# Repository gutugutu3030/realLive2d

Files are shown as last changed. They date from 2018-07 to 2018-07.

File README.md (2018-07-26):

# realLive2d
gif
## reallive2dSimulator
Processing　設計ソフト＋シミュレータ

縮尺は 1pixel = 0.1mm
一応シリアル通信機能はついているがv1用　現状のプログラムでは使用できないので注意

使用ライブラリ：controlP5

## Servo16
Arduino実行ファイル．上記の理由に付き基本的にはこっちをいじったほうが良い
こっちはstandalone関数内に書くと良さげ
usingEEPROMフラグでレイヤの移動量をEEPROMから読むかソースコードの値を参照するかを決定できる

使用ライブラリ：秋月電子のPCA9685.zip，[Skywriter Arduino Library](https://github.com/pimoroni/skywriter-hat/tree/master/arduino)，[SparkFun GridEYE Arduino Library](https://github.com/sparkfun/SparkFun_GridEYE_Arduino_Library), EEPROM

## explore
顔のパラメータを変更可能　上記のEEPROMモードにてパラメータ書き込みをするソフトもこれが担当する

マウス座標に顔が向くようになっている　上のスライダにて各レイヤの移動量を変更できる．移動量はキー操作でEEPROMに書き込みができる

## timeline
5秒間，各レイヤの動きを記録，再生できる
簡単なタイムラインインターフェースからなっている
sキーで保存，lキーで読み込みが可能

## deteilsaver
キャリブレーション用システム
Servo16_deteilsaverを書き込んだ状態で起動することで，サーボの角度のキャリブレーションができる

## DOASerial.py
python2.7必須
Arduinoのシリアルポートに設定することで聴覚を与えることができる
use [ReSpeaker USB 4 Mic Array](https://github.com/respeaker/usb_4_mic_array/)

## 3dmodels
使用した3Dモデル一覧

| name | 説明 |
----|----
| hone.stl | サーボモータのホーン拡張用 |
| servoHone.scad | hone.stlの元データ |
| line.scad | 4連サーボのデータ　サーボのモデルデータ込 |
| v2.scad | v2プレートのデータ　要line.scad |
| v2.stl | v2プレートのデータ |
| v2-arm.scad | セパレータ（透明の板）を保持するアームfor v2 の元データ|
| v2-arm.stl | セパレータを保持するアームfor v2|

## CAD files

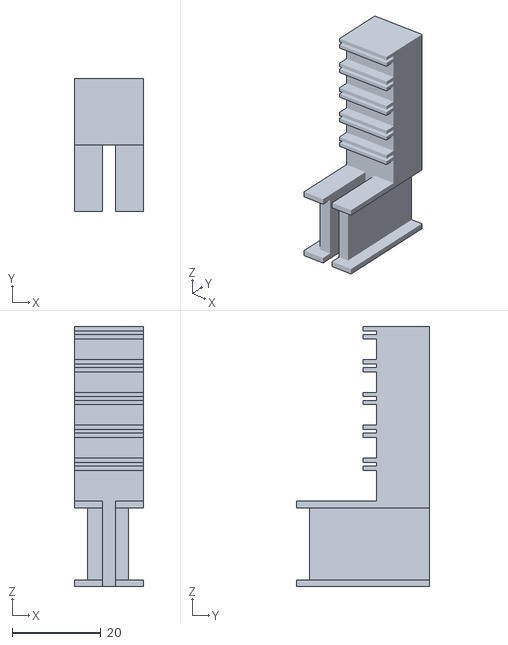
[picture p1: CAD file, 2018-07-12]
3dmodels/v2-arm.stl
15.6 x 30.0 x 58.5

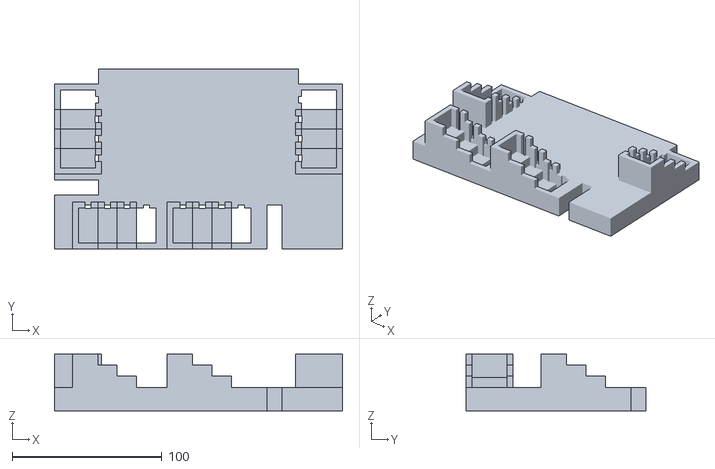
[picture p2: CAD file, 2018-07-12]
3dmodels/v2.stl
192.4 x 120.0 x 38.0

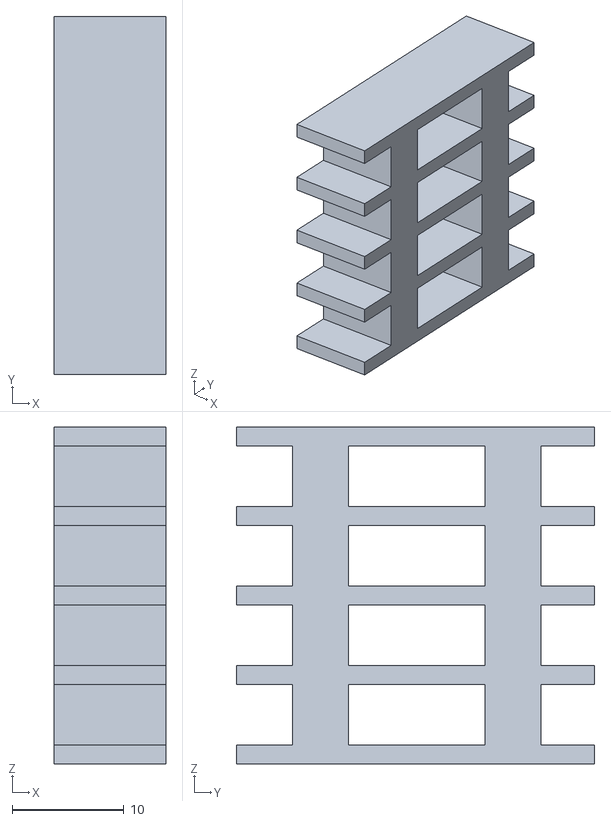
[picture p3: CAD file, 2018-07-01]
3dmodels/arm.stl
10.0 x 32.0 x 30.1

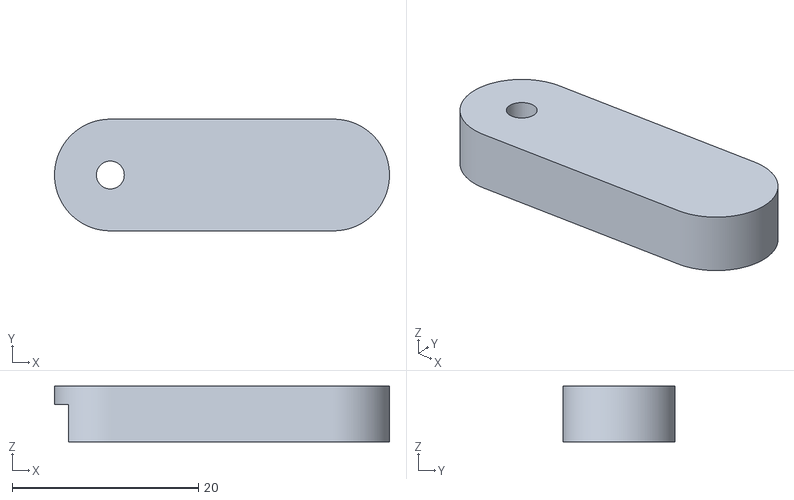
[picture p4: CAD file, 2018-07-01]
3dmodels/hone.stl
36.0 x 12.0 x 6.00

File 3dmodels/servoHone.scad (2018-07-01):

honeh=4;

difference(){
    union(){
        cylinder(r=6,h=6,$fn=180);
        translate([30-6,0,0])
        cylinder(r=6,h=6,$fn=180);
        translate([0,-6,0])
        cube([30-6,12,6]);
    }
    union(){
        translate([-10,-4,0])
        cube([30,8,honeh]);
        cylinder(r=1.5,h=100,$fn=50);
    }
}

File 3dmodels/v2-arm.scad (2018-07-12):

include<line.scad>
//echo(servo*4+waku*2-0.4);
//translate([-10,0,0])
//cube([10-0.4,servoH+waku-0.4,(2.4+5)*4+15.8+2.4]);
//hikkake(l=10-0.4,d=2,thin=1,fixPos=false);
//servo();


waku1=3;

difference(){
    union(){
        cube([10-0.4,servoH+waku-0.4,15.8+0.4]);
        translate([0,15,0])
        {
            cube([10-0.4,servoH+waku-0.4-15,(2.4+5)*5+15.8+2.4+1+0.8]);
            hikkake(l=10-0.4,d=3,thin=1,fixPos=false);
        }
        translate([-waku1,-waku1,-1.5])
            cube([10-0.4+waku1*2,servoH+waku-0.4+waku1,1.5]);
        translate([-waku1,-waku1,15.8+0.4])
            cube([10-0.4+waku1*2,servoH+waku-0.4+waku1,1.5]);
        //servo4_0();
    }
    translate([(10-0.4-5)/2,-waku1,-50])
    cube([5,15+waku1,70]);
}

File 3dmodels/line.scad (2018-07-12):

//cube([100,100,15.8]);

servoW=12.6+0.4;
servoH=23.0+0.4;
    waku=4;

module servo(){
    cube([12.6+0.4,23.0+0.4,26.7]);
    translate([0,(23.0-32.4)/2,15.8])
    cube([12.6+0.4,32.4,2.4]);
    translate([(13-4.2)/2,23,-100])
    cube([4.2,5,18+100]);
}

module servo4_0(){
translate([servoW*4,0,0])
scale([-1,1,1])
    for(i = [0:3]){
        translate([i*13,0,(2.4+5)*i]){
            servo();
        }
    }
}

module servo4(){
translate([servoW*4,0,0])
scale([-1,1,1])
difference(){
union(){
    translate([-waku,-waku,0])
    cube([waku,waku*2+servoH,15.8]);
    translate([0,-waku,0]){
    for(i = [0:3]){
        translate([i*13,0,0]){
            cube([waku+servoW,waku*2+servoH,15.8+(2.4+5)*i]);
        }
    }
    }
}


union(){
    for(i = [0:3]){
        translate([i*13,0,(2.4+5)*i]){
            servo();
        }
    }
    
}
}
}

module servo4_rect(l=servoW*4+waku*2){
    translate([-waku,-waku,0])
    cube([l,servoH+waku+2,15.8]);

}


module hikkake(l=servoW*4,d=10,fixPos=true,haba=0.8,thin=2){
    x=0;
    if(fixPos){
        x=-waku;
    }
    for(i=[1:5]){
        translate([0,-d,(2.4+5)*i+15.8+2.4-thin])
            cube([l,d,thin]);  
        translate([0,-d,(2.4+5)*i+15.8+2.4+haba])
            cube([l,d,thin]);  
    }

}

//servo4_0();
//servo();
//hikkake();
//

//for(i=[0:4]){
//translate([-waku,waku+servoH,(2.4+5)*i+15.8+2.4])
//cube([servoW*4,10,2]);
//}
//translate([-waku,waku+servoH,(2.4+5)+15.8+2.4])
//cube([servoW*2+waku,10,2]);
//translate([-waku,waku+servoH,(2.4+5)*2+15.8+2.4])
//cube([servoW+waku,10,2]);
//
//translate([100,0,0])
//servo4_rect();
//
//translate([0,50,0])
//servo4_rect();

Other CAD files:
3dmodels/v2.scad

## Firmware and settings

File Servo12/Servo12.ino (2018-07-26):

#include <EEPROM.h>
#include <Wire.h>
#include <SparkFun_GridEYE_Arduino_Library.h>
#include <PCA9685.h>            //PCA9685用ヘッダーファイル（秋月電子通商作成）
#include <skywriter.h>

bool usingEEPROM = true;

PCA9685 pwm = PCA9685(0x40);    //PCA9685のアドレス指定（アドレスジャンパ未接続時）

GridEYE grideye;//サーモセンサ

#define SERVOMIN 51            //最小パルス幅 (標準的なサーボパルスに設定)
#define SERVOMAX 255            //最大パルス幅 (標準的なサーボパルスに設定)
#define BUFFERSIZE 100
#define LAYER_LENGTH 3
#define SERVO_NUM 12

int amount[LAYER_LENGTH] = {30, -22, 50}; //usingEEPROM=falseのときに使用される値
int defaultAngle[SERVO_NUM] = {24, 35, 25, 18, 16, 24, 30, 23, 22, 23, 0, 23/*, 26, 13, 25, 31*/};
//レイヤー2可動サーボが時々プラ版に引っかかるため，動作を制限する
int maxmin[LAYER_LENGTH][2] = {{95, 0}, {100, 15}, {100, 0}};


//0 - 100
int layerX[LAYER_LENGTH] = {50, 50, 50};
int layerY[LAYER_LENGTH] = {50, 50, 50};


//開始命令＋終了命令：0
//1~181までの数値を受け取る

void setup() {
  Serial.begin(57600);
  delay(500);
  pwm.begin();                   //初期設定 (アドレス0x40用)
  pwm.setPWMFreq(20);            //PWM周期を60Hzに設定 (アドレス0x40用)
  delay(500);
  Skywriter.begin(4, 5);
  Skywriter.onXYZ(handle_xyz);
  delay(50);
  grideye.begin();
  if (usingEEPROM) {
  Serial.println("layerAmount:");
    for (int i = 0; i < LAYER_LENGTH; i++) {
      amount[i] = EEPROM[i] - 50;
      Serial.print(amount[i]);
      Serial.print(" ");
    }
    Serial.println();
  }
}

unsigned long lastReceivingTime = 0;

void loop() {
  if (Serial.available()) {
    byte buffer[BUFFERSIZE];
    int length = Serial.readBytesUntil(0, buffer, BUFFERSIZE);
    if (length != 0) {
      if (exploreEvent(buffer[0], buffer + 1, length - 1)) {
        lastReceivingTime = millis();
      }
    }
  }
  if (millis() - lastReceivingTime > 3000) {
    standalone();
  }
}


void servo_write(int ch, int ang) { //動かすサーボチャンネルと角度を指定
  ang = map(ang, 0, 180, SERVOMIN, SERVOMAX); //角度（0～180）をPWMのパルス幅（150～600）に変換
  pwm.setPWM(ch, 0, ang);
  //delay(1);
}

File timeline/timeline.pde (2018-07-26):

import controlP5.*;
import processing.serial.*;
import java.util.*;

final byte COMMAND_EXPLORE=0x01;
int layerNum=3;
boolean usingSerial=true;

Serial arduino;
ControlP5 cp5;

int timeIndex=0;
boolean playing=false;

Timeline t[]=new Timeline[layerNum*2];
Timeline selectedTimeline=null;

int amount[]=new int[layerNum*2];

void setup() {
  size(1600, 1600);
  cp5 = new ControlP5(this);
  for (int i=0; i<t.length; i++) {
    t[i]=new Timeline(50, i*200, width-200, 200, 100);
    cp5.addSlider("layerAmount_"+i).setPosition(width-100, i*200).setSize(100, 180).setRange(-50, 50).setValue(amount[i]).setId(i);
  }
  if (usingSerial) {
    arduino=new Serial(this, "COM8", 57600);
  }

  frameRate(60);
}

void draw() {
  if (playing&&frameCount%3==0) {
    timeIndex++;
  }

  for (Timeline t1 : t) {
    t1.draw();
  }
  strokeWeight(3);
  stroke(0);
  for (int i=0; i<layerNum*2; i++) {
    line(0, i*200, width, i*200);
  }
  if (usingSerial&&frameCount%5==0) {
    arduino.write(COMMAND_EXPLORE);
    for (int i=0; i<layerNum*2; i++) {
      arduino.write(t[i].getValue(amount[i]));
      print(t[i].getValue(amount[i])+" ");
    }
    println();
    arduino.write(0);
  }
}

void mousePressed() {
  for (Timeline t1 : t) {
    if (t1.ifin()) {
      selectedTimeline=t1;
      break;
    }
  }
}

void mouseDragged() {
  if (selectedTimeline!=null) {
    selectedTimeline.drag();
  }
}

void mouseReleased(){
  selectedTimeline=null;
}

void keyReleased() {
  if (key==' ') {
    if (playing) {
      playing=false;
    } else {
      playing=true;
      timeIndex=0;
    }
  }
  if (key=='s') {
    String lines[]=new String[layerNum*2];
    for (int i=0; i<lines.length; i++) {
      lines[i]="";
      for (int j=0; j<t[i].data.length; j++) {
        if (j!=0) {
          lines[i]+=",";
        }
        lines[i]+=t[i].data[j];
      }
      lines[i]+=":"+amount[i];
    }
    saveStrings("data.text", lines);
  }
  if (key=='l') {
    String lines[]=loadStrings("data.text");
    for (int i=0; i<lines.length; i++) {
      String sp[]=lines[i].split(":");
      String data[]=sp[0].split(",");
      for (int j=0; j<data.length; j++) {
        t[i].data[j]=int(data[j]);
      }
      amount[i]=int(sp[1]);
      cp5.getController("layerAmount_"+i).setValue(amount[i]);
    }
  }
}

class Timeline {
  int data[];
  int width, height;
  int x, y;
  float scale=1;
  Timeline(int x, int y, int width, int height, int dataLength) {
    data=new int[dataLength];
    scale=1.0*(dataLength-1)/(width-1);
    this.width=width;
    this.height=height;
    this.x=x;
    this.y=y;
  }
  void draw() {
    strokeWeight(1);
    stroke(0);
    fill(255);
    rect(x, y, width, height);
    stroke(200);
    line(x, y+height/2, x+width, y+height/2);
    strokeWeight(2);
    noFill();
    stroke(0, 0, 100);
    beginShape();
    for (int i=0; i<data.length; i++) {
      vertex(x+i/scale, y+height/2-data[i]);
    }
    endShape();
    strokeWeight(1);
    stroke(255, 0, 0);
    {
      int x1=(int)(x+timeIndex%data.length/scale);
      line(x1, y, x1, y+height);
    }
  }
  void drag() {
    int x1=min(max(mouseX-x, 0), width-1);
    int y1=height/2-min(max(mouseY-y, 0), height);
    data[(int)(x1*scale)]=y1;
  }
  boolean ifin() {
    return x<=mouseX&&mouseX<x+width&&y<=mouseY&&mouseY<y+height;
  }
  int getValue(int amount) {
    //println((timeIndex%data.length)+" "+data[timeIndex%data.length]);
    return data[timeIndex%data.length]*amount/height+51;
  }
}

void controlEvent(ControlEvent theEvent) {
  if (theEvent.isController()) {
    // check if theEvent is coming from a boxsize controller
    if (theEvent.controller().getName().startsWith("layerAmount_")) {
      // get the id of the controller and map the value
      // to an element inside the boxsize array.
      int id = theEvent.controller().getId();
      if (id>=0 && id<amount.length) {
        amount[id] = (int)theEvent.getValue();
      }
    }
  }
}

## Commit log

2018-07-01 テストコード
2018-07-01 add 3dmodel
    [arm.stl, hone.stl, servoHone.scad]
2018-07-02 skywriter追加
    RCフィルタの係数適当でござる
2018-07-02 readme更新
2018-07-05 change frameRate
2018-07-07 穴 貫通
    [line.scad, v2.scad, v2.stl]
2018-07-07 fix 3d model
    アームデータ更新
    土台3Dモデル修正（配線用の穴あけ）
    [line.scad, v2-arm.scad, v2-arm.stl]
2018-07-08 fix 3d model
    [v2-arm.stl, v2.scad, v2.stl]
2018-07-09 初回起動時にタッチ認識されないのを直した
2018-07-11 シリアル方法改善
    pythonちょっとわからない
2018-07-12 キャリブレーション用プログラム追加
2018-07-12 change UNO
    v2材料不足によりとりあえずUNOでテスト 行けそうならA*に変更
2018-07-13 やっぱりA*に戻した
    キャリブレーションだん
2018-07-13 create getHotPixel()関数
2018-07-13 ライブラリ表記追記
2018-07-14 キャリブレーション時干渉対策モード追加
2018-07-14 人認識処理追加
    TODO：再度servo-3のキャリブレーション
2018-07-14 再キャリブレーション
    レイヤーを減らした
    それに合わせてサーボを4個減らした
2018-07-17 hotpixel 座標軸・閾値修正
2018-07-17 探索用スケッチ作成
2018-07-18 目の動きを修正
    より良くしてみたｗ
2018-07-18 最低限インターフェース作った
2018-07-18 timelineSystem作成
2018-07-18 save load昨日 仮作成
2018-07-19 UI修正
2018-07-24 Arduino側プログラム統一化
2018-07-25 サーボの可動域を制限できるようにした
    とりあえず自壊しないようにした
2018-07-25 とりあえずコンソールに出力
2018-07-25 readme更新
    ついでにtimeline修正
2018-07-25 変更し忘れてた
2018-07-26 serial修正
    exploreも一部修正
2018-07-26 timelineのスライダロード後反映されない問題解決
